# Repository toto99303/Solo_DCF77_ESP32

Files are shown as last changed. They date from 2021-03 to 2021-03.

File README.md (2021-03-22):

# Solo DCF77 ESP32 transmitter
So what is this? It's a standalone DCF77 transmitter designed to be used with any wrist watch that is capable of receiving the signal. (Casio Wave Ceptor series etc.)

#### Features:
- Connects to your local WiFi network.
- Syncs the exact time via NTP and converts it to DCF77 signal.
- Shows the realtime data on the OLED display live.
- Uses screensavers to protect the screen from burn-in. (changes every minute)
- 3D printable stand.

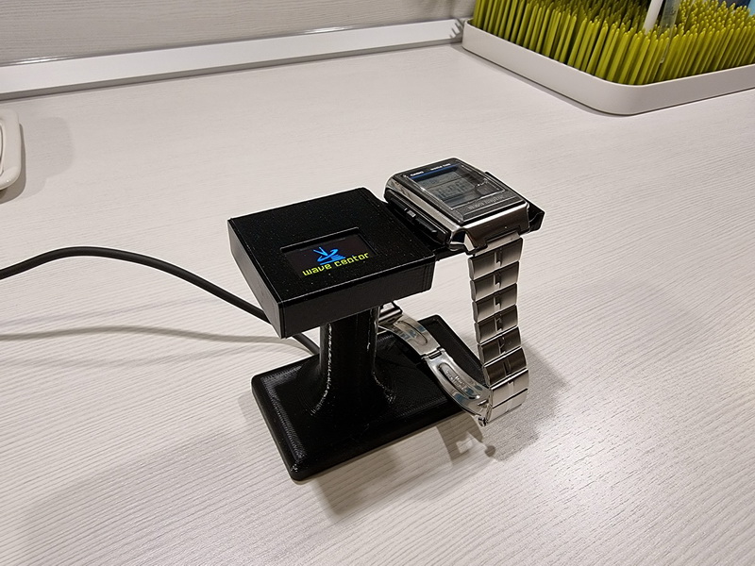
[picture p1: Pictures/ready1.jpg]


### PCB and full BOM:

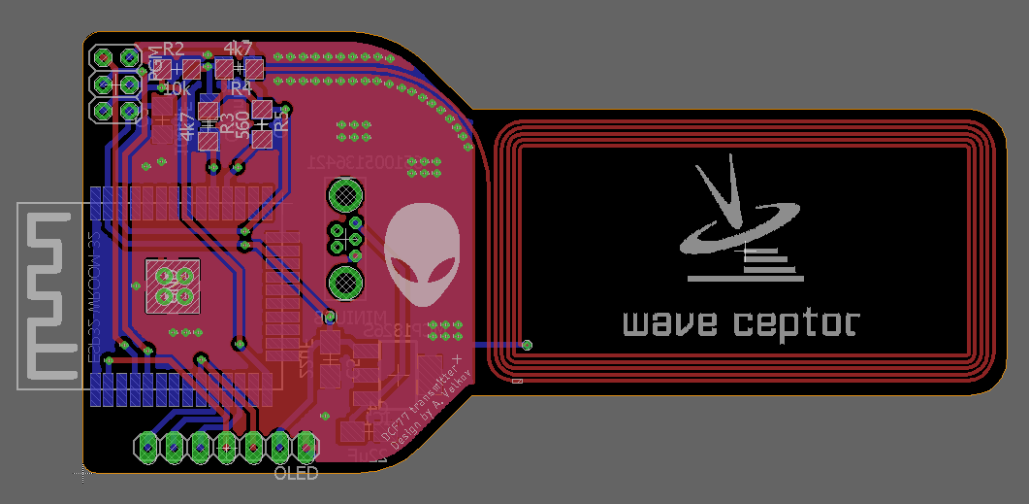
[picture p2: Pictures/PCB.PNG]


The original Eagle design files are included as well as exported GERBER files for direct PCB production.

BOM:
- 1 x ESP32-WROOM-32 barebone
- 1 x 7 Pin SPI 0.96" Dual Color Yellow Blue OLED Display Module SSD1306 (https://hacktronics.co.in/lcd-displays/7-pin-spi-iic-096-dual-color-yellow-blue-oled-display-module-ssd1306)
- 1 x Mini USB female vertical TH (https://store.comet.bg/download-file.php?id=18384)
- 1 x MCP1826S-3302E/DB voltage regulator (https://store.comet.bg/download-file.php?id=4147)
- 3 x TANT B SMD 22uF 16V caps
- 2 x C1206 100nF 50V caps
- 2 x R1206 10K resistors
- 2 x R1206 4.7K resistors
- 1 x R1206 560R resistor

### Firmware
To upload the sketch you will need USB to serial UART converter capable of supplying 3.3V VCC.
Pinout for the header:
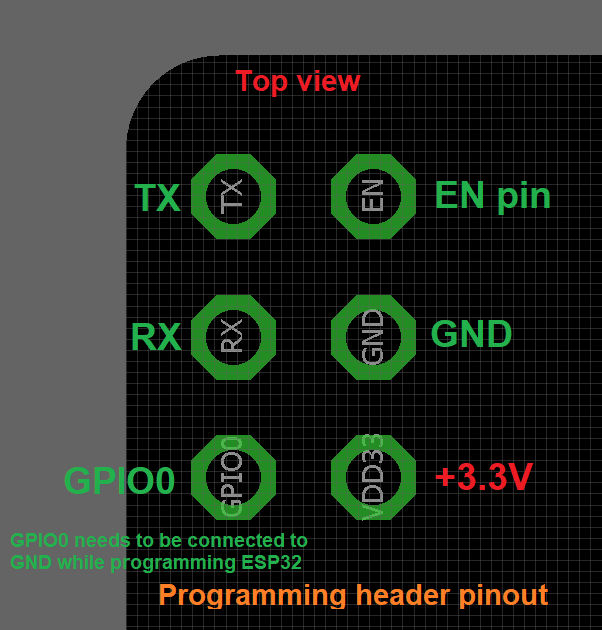
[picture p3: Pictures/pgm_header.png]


Remember that in order to boot the EPS32 in programming mode you will need to connect GPIO0 pin to GND (Low).

1. Open the sketch in Arduino IDE and edit your wifi SSID and password.
2. Use board "WEMOS LOLIN32" at 80Mhz flash frequency. (Tools -> Board)
3. Compile and upload.

### 3D printable stand

The original design file from Fusion360 is available as well as ready to print STLs.
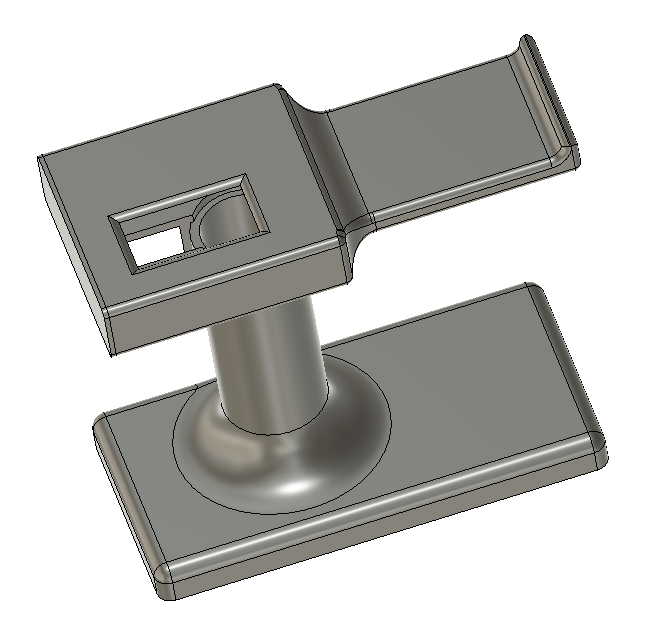
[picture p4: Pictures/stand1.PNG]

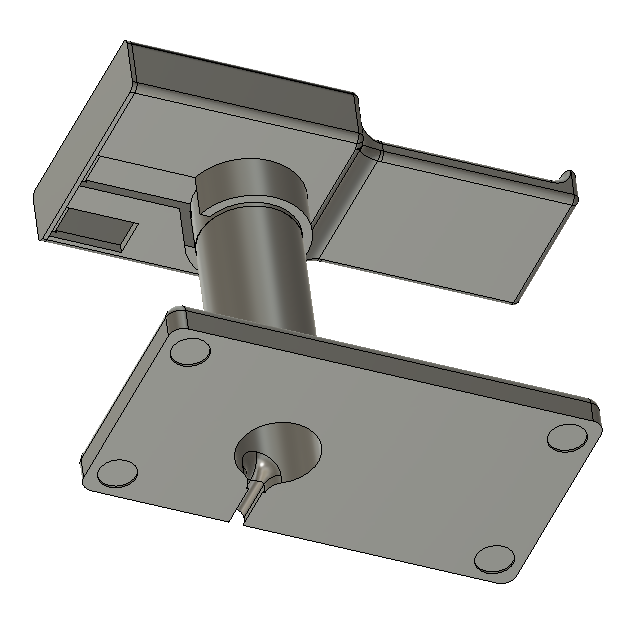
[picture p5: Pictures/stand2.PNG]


### Video:

DCF77 transmitter - demo (https://youtu.be/RjWDWWJ56to)

### More Pictures:

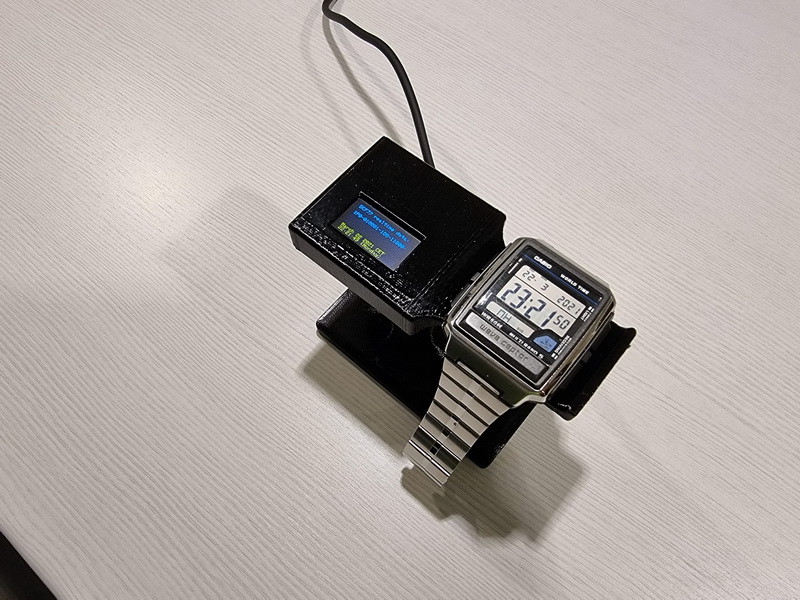
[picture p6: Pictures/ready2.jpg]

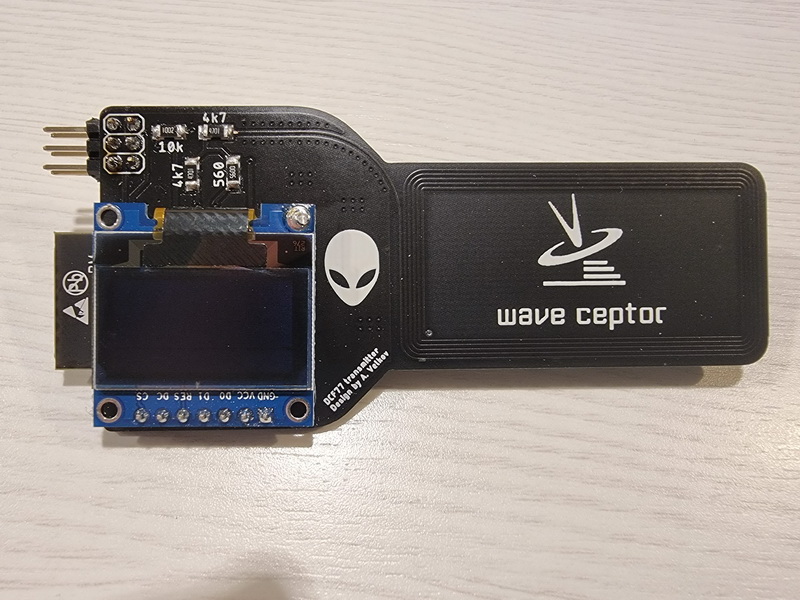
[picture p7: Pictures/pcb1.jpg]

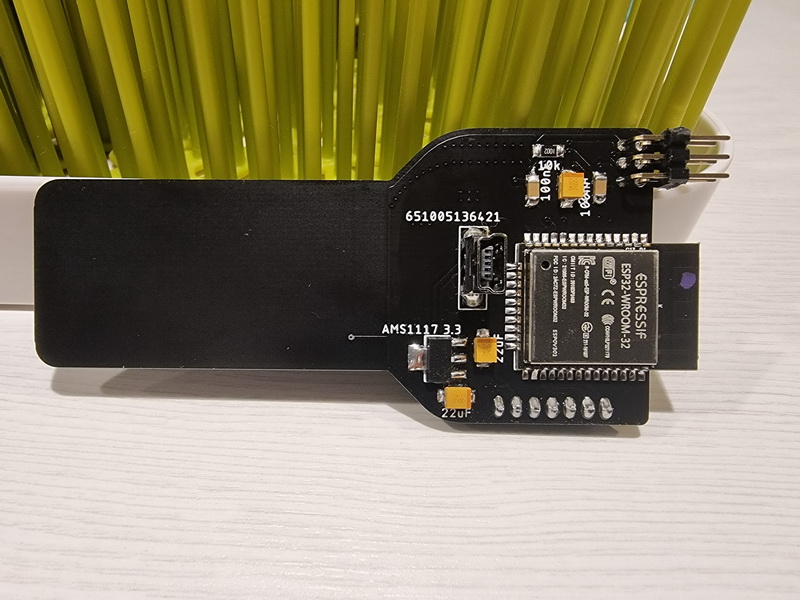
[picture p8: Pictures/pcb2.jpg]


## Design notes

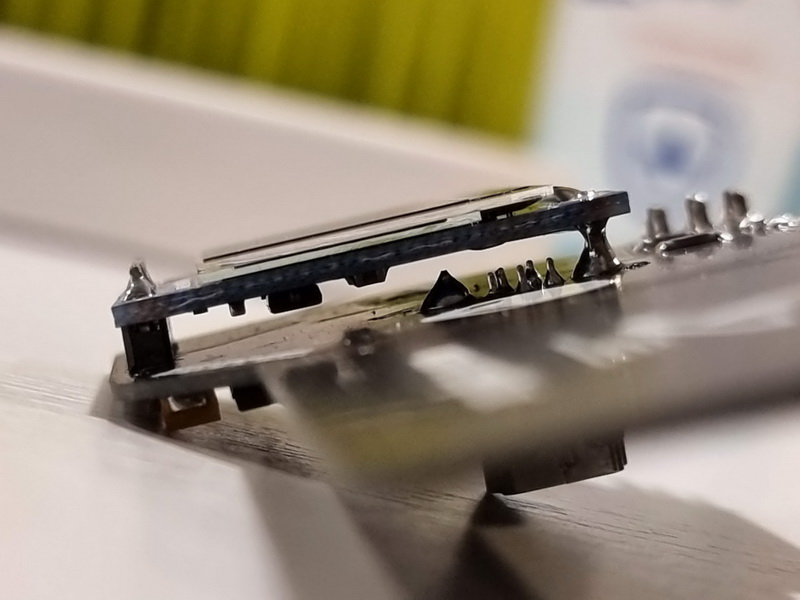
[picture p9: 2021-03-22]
Pictures/oled.jpg

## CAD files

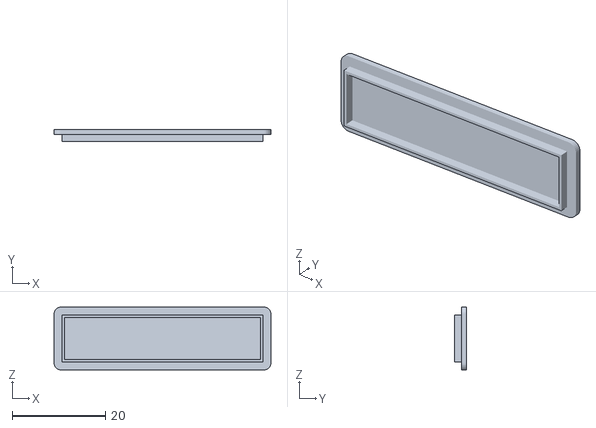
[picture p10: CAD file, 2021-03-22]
Watch stand (3D design)/STL/Cap.stl
46.5 x 2.50 x 13.5

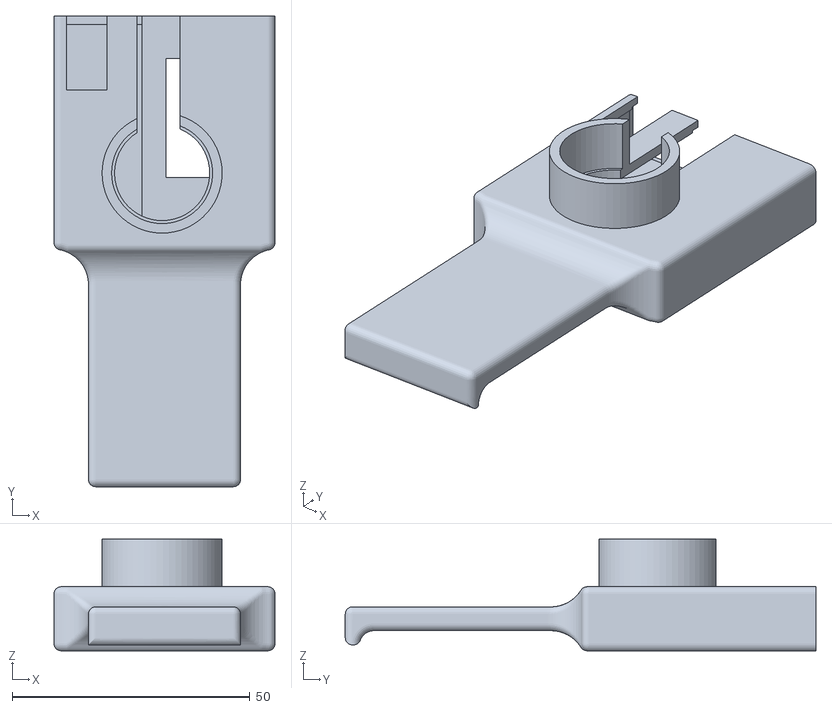
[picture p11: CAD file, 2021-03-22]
Watch stand (3D design)/STL/Top_holder.stl
46.5 x 99.0 x 23.5

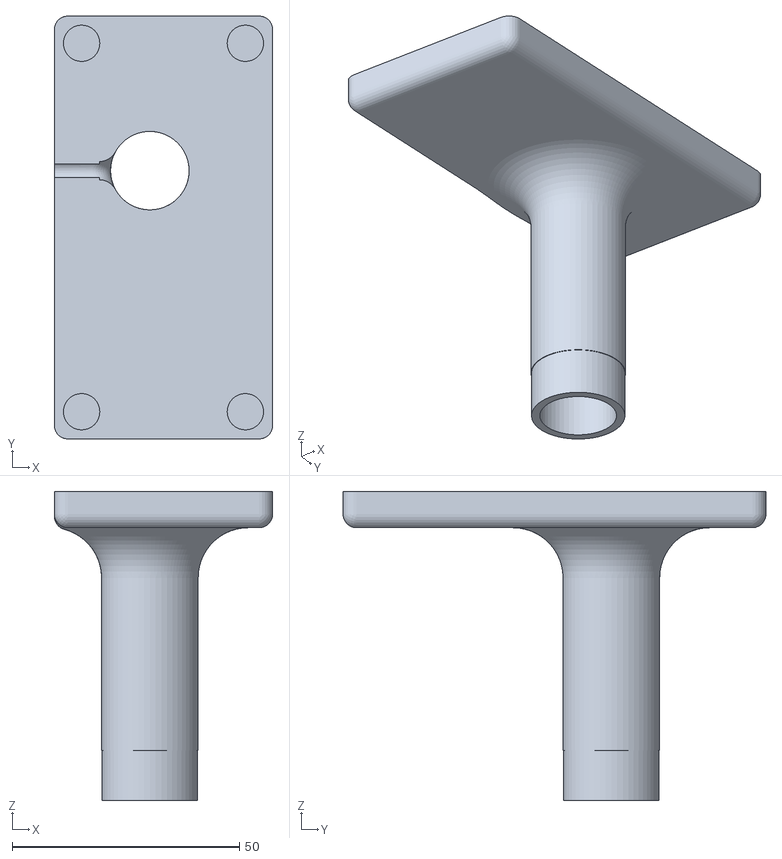
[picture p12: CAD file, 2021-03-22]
Watch stand (3D design)/STL/Bottom_stand.stl
48.0 x 93.0 x 68.0

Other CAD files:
Watch stand (3D design)/Fusion360/Solo_DCF77_ESP32_stand.f3d

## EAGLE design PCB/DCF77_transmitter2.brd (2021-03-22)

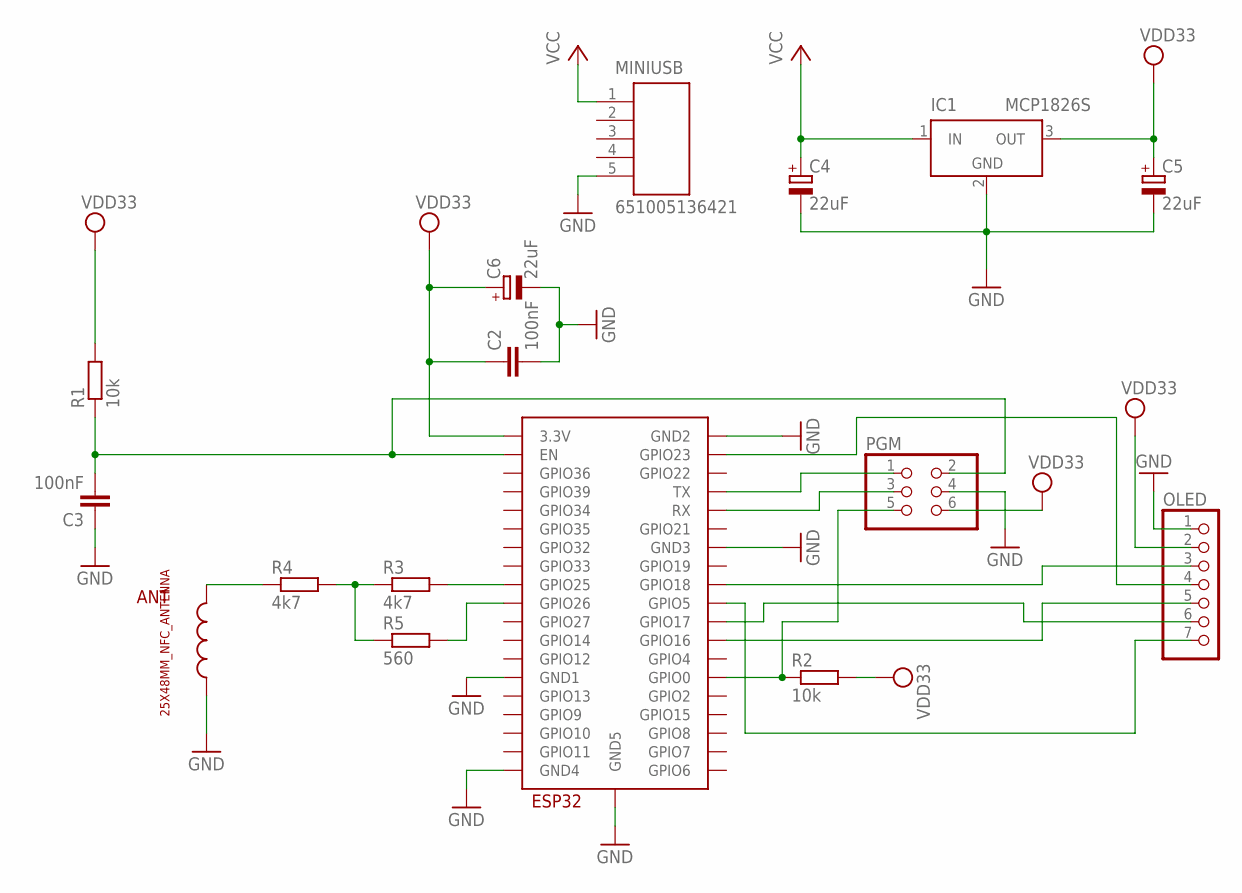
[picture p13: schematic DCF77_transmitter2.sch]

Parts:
ANT: 25X48MM_NFC_ANTENNA
C2, C3: 100nF; C1206
C4, C5, C6: 22uF; B/3528-21W
IC1: MCP1826S; SOT223
MINIUSB: 651005136421
OLED: PINHD-1X7; 1X07
PGM: PINHD-2X3; 2X03
R1, R2: 10k; R1206
R3, R4: 4k7; R1206
R5: 560; R1206
U$2: ESP32-WROOM

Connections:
EN: C3.2, PGM.2, R1.1, U$2.EN
GND: ANT.P$2, C2.2, C3.1, C4.-, C5.-, C6.-, IC1.2 (GND), IC1.4 (GND), MINIUSB.5, OLED.1, PGM.4, U$2.GND1, U$2.GND2, U$2.GND3, U$2.GND4, U$2.GND5
GPIO0: PGM.5, R2.1, U$2.IO0 (GPIO0)
GPIO5: OLED.7, U$2.IO5 (GPIO5)
GPIO16: OLED.5, U$2.IO16 (GPIO16)
GPIO17: OLED.6, U$2.IO17 (GPIO17)
GPIO18: OLED.3, U$2.IO18 (GPIO18)
GPIO23: OLED.4, U$2.IO23 (GPIO23)
unnamed: R5.2, U$2.IO26 (GPIO26)
unnamed: R3.2, U$2.IO25 (GPIO25)
unnamed: R3.1, R4.2, R5.1
unnamed: ANT.P$1, R4.1
RX: PGM.3, U$2.RX
TX: PGM.1, U$2.TX
VCC: C4.+, IC1.1 (IN), MINIUSB.1
VDD33: C2.1, C5.+, C6.+, IC1.3 (OUT), OLED.2, PGM.6, R1.2, R2.2, U$2.3V3 (3.3V)

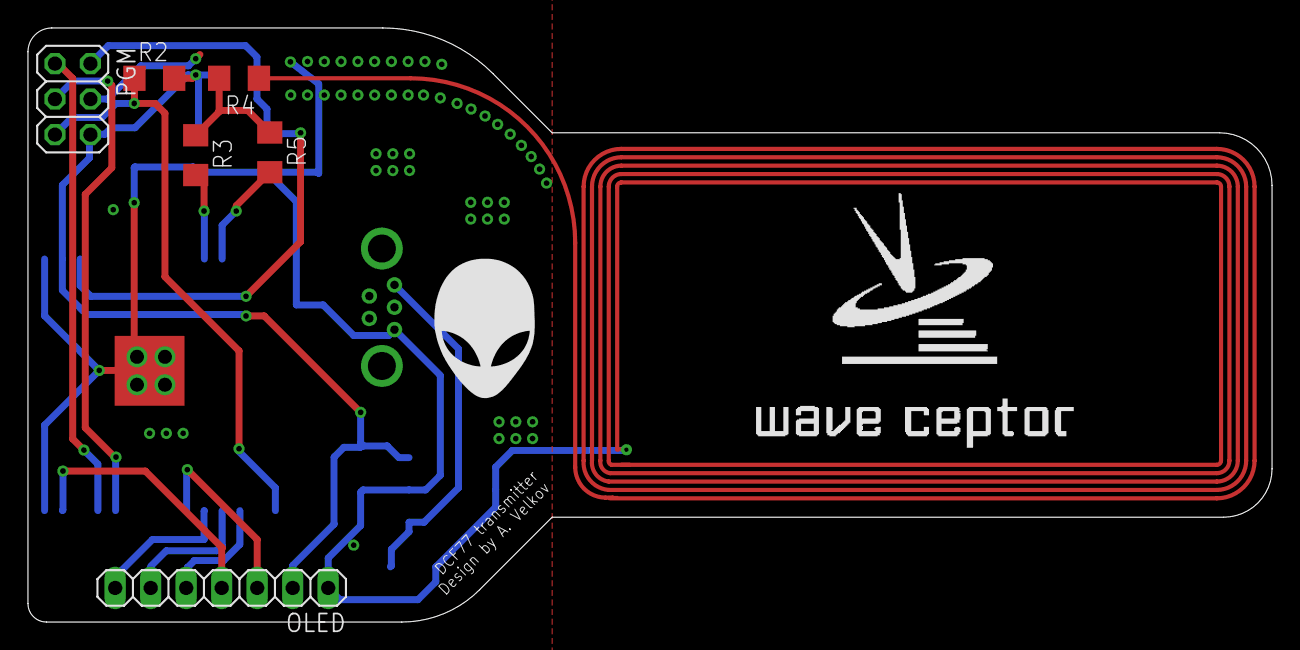
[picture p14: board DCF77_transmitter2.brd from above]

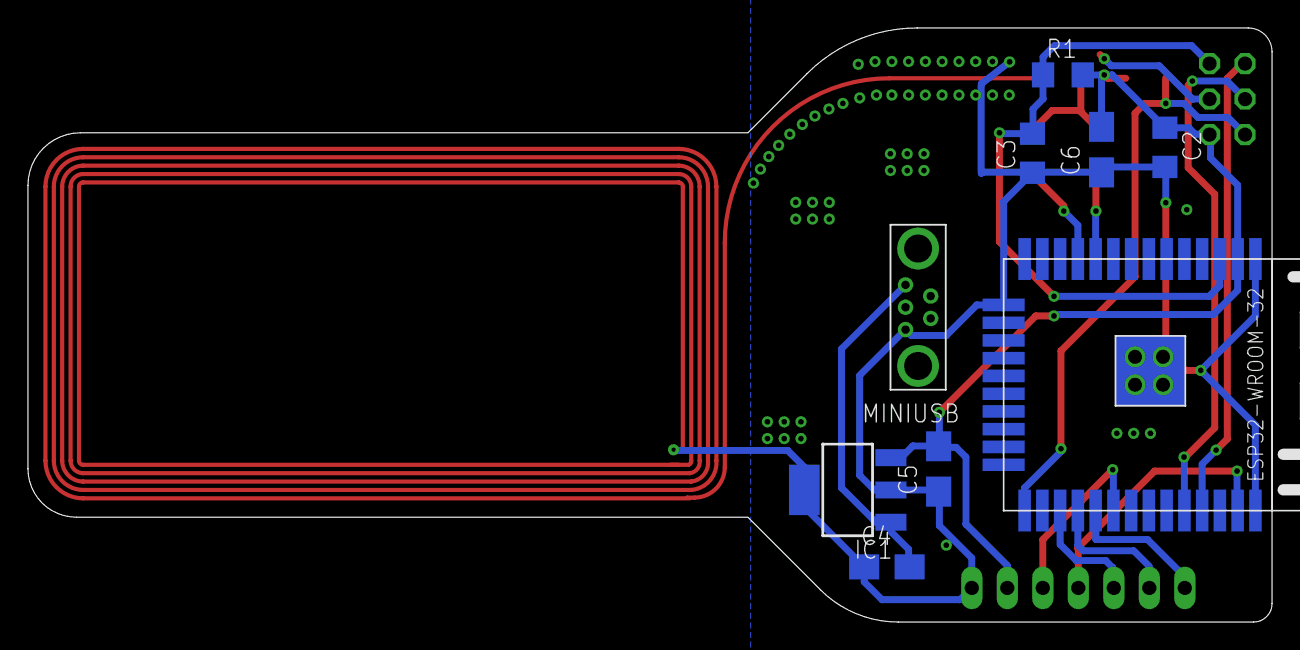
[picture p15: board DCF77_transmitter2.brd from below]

Board: 2 copper layers, 89.0 x 42.5 mm, 16 parts (9 on the bottom side), 16 nets.

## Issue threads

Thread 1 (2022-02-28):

gerber silkscreen vreg ams1117-3.3

Amstrad-nutter, 2022-02-28:
The gerber silkscreen shows vreg ams1117-3.3 which is a common almost generic device but cannot be used "Correct footprint but incorrect pinout.
the BOM listed MCP1826S-3302E with the less common pinout. this works
please recheck your components against the BOM not blindly follow the silkscreen as i did?.

danybd, 2023-05-23:
I had the same issue while reproducing the project. I ordered and built the wrong voltage regulator due to the confusing silkscreen. After some trouble shooting found out that the regulator is not pin compatible.

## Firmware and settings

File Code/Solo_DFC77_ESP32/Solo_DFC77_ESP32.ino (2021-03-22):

/*
  Based on this sketch: https://github.com/SensorsIot/DCF77-Transmitter-for-ESP32
  from Andreas Spiess (the guy with the swiss accent :)

  Modified for my custom Solo DCF77 PCB using ESP32 and SPI OLED display.

  22.03.2021 Antonio Velkov
*/


#include <WiFi.h>
#include <Ticker.h>
#include <Time.h>
#include <Wire.h>  // Only needed for Arduino 1.6.5 and earlier
#include <Adafruit_GFX.h>
#include <Adafruit_SSD1306.h>

//OLED config
#define SCREEN_WIDTH 128 // OLED display width, in pixels
#define SCREEN_HEIGHT 64 // OLED display height, in pixels

#define OLED_MOSI   23
#define OLED_CLK   18
#define OLED_DC    17
#define OLED_CS    5
#define OLED_RESET 16

Adafruit_SSD1306 display(SCREEN_WIDTH, SCREEN_HEIGHT,OLED_MOSI, OLED_CLK, OLED_DC, OLED_RESET, OLED_CS);

// Wifi credentials
const char* ssid = "yourSSID";
const char* password = "yourPassword";
                          
#define LEDBUILTIN 26
#define ANTENNAPIN 25

Ticker tickerDecisec; // TBD at 100ms

//complete array of pulses for a minute
//0 = no pulse, 1=100ms, 2=200ms

int impulseArray[60];
int impulseCount = 0;
int actualHours, actualMinutes, actualSecond, actualDay, actualMonth, actualYear, DayOfW;
int timeRunningContinuous = 0;

const char* ntpServer = "bg.pool.ntp.org"; // enter your closest pool or pool.ntp.org
const char* TZ_INFO    = "CET-1CEST-2,M3.5.0/02:00:00,M10.5.0/03:00:00";  // enter your time zone (https://remotemonitoringsystems.ca/time-zone-abbreviations.php)


struct tm timeinfo;

String time_data;
int screensaver = 0;

//Casio Wave Ceptor custom logo
static const unsigned char PROGMEM logo_bmp[] =
{
  0x00, 0x00, 0x00, 0x00, 0x00, 0x00, 0x01, 0x80, 0x00, 0x00, 0x00, 0x00, 0x00, 0x00, 0x00, 0x00, 
  0x00, 0x00, 0x00, 0x00, 0x00, 0x00, 0x00, 0x80, 0x00, 0x00, 0x00, 0x00, 0x00, 0x00, 0x00, 0x00, 
  0x00, 0x00, 0x00, 0x00, 0x00, 0x00, 0x00, 0x80, 0x00, 0x00, 0x00, 0x00, 0x00, 0x00, 0x00, 0x00, 
  0x00, 0x00, 0x00, 0x00, 0x00, 0x10, 0x00, 0x80, 0x00, 0x00, 0x00, 0x00, 0x00, 0x00, 0x00, 0x00, 
  0x00, 0x00, 0x00, 0x00, 0x00, 0x18, 0x00, 0x80, 0x00, 0x00, 0x00, 0x00, 0x00, 0x00, 0x00, 0x00, 
  0x00, 0x00, 0x00, 0x00, 0x00, 0x08, 0x00, 0x80, 0x00, 0x00, 0x00, 0x00, 0x00, 0x00, 0x00, 0x00, 
  0x00, 0x00, 0x00, 0x00, 0x00, 0x04, 0x00, 0x80, 0x00, 0x00, 0x00, 0x00, 0x00, 0x00, 0x00, 0x00, 
  0x00, 0x00, 0x00, 0x00, 0x00, 0x06, 0x00, 0xc0, 0x00, 0x00, 0x00, 0x00, 0x00, 0x00, 0x00, 0x00, 
  0x00, 0x00, 0x00, 0x00, 0x00, 0x02, 0x00, 0xc0, 0x00, 0x00, 0x00, 0x00, 0x00, 0x00, 0x00, 0x00, 
  0x00, 0x00, 0x00, 0x00, 0x00, 0x01, 0x00, 0xc0, 0x00, 0x00, 0x00, 0x00, 0x00, 0x00, 0x00, 0x00, 
  0x00, 0x00, 0x00, 0x00, 0x00, 0x01, 0x80, 0xc0, 0x00, 0x00, 0x00, 0x00, 0x00, 0x00, 0x00, 0x00, 
  0x00, 0x00, 0x00, 0x00, 0x00, 0x00, 0xc0, 0xc0, 0x00, 0x00, 0x00, 0x00, 0x00, 0x00, 0x00, 0x00, 
  0x00, 0x00, 0x00, 0x00, 0x00, 0x00, 0xc0, 0xc0, 0x00, 0x00, 0x00, 0x00, 0x00, 0x00, 0x00, 0x00, 
  0x00, 0x00, 0x00, 0x00, 0x00, 0x00, 0x60, 0xc0, 0x00, 0x00, 0x00, 0x00, 0x00, 0x00, 0x00, 0x00, 
  0x00, 0x00, 0x00, 0x00, 0x00, 0x00, 0x30, 0xe0, 0x00, 0x00, 0x00, 0x00, 0x00, 0x00, 0x00, 0x00, 
  0x00, 0x00, 0x00, 0x00, 0x00, 0x00, 0x38, 0xe0, 0x00, 0x00, 0x00, 0x00, 0x00, 0x00, 0x00, 0x00, 
  0x00, 0x00, 0x00, 0x00, 0x00, 0x00, 0x1c, 0xe0, 0x00, 0x00, 0x00, 0x00, 0x00, 0x00, 0x00, 0x00, 
  0x00, 0x00, 0x00, 0x00, 0x00, 0x00, 0x1e, 0xe0, 0x00, 0x7e, 0x00, 0x00, 0x00, 0x00, 0x00, 0x00, 
  0x00, 0x00, 0x00, 0x00, 0x00, 0x00, 0x0f, 0xe0, 0x07, 0xff, 0xc0, 0x00, 0x00, 0x00, 0x00, 0x00, 
  0x00, 0x00, 0x00, 0x00, 0x00, 0x00, 0x07, 0xf0, 0x00, 0x1f, 0xc0, 0x00, 0x00, 0x00, 0x00, 0x00, 
  0x00, 0x00, 0x00, 0x00, 0x00, 0x00, 0x07, 0xf0, 0x00, 0x1f, 0xc0, 0x00, 0x00, 0x00, 0x00, 0x00, 
  0x00, 0x00, 0x00, 0x00, 0x00, 0x00, 0x03, 0xf0, 0x00, 0x3f, 0x80, 0x00, 0x00, 0x00, 0x00, 0x00, 
  0x00, 0x00, 0x00, 0x00, 0x00, 0x00, 0x03, 0xf0, 0x00, 0x7f, 0x00, 0x00, 0x00, 0x00, 0x00, 0x00, 
  0x00, 0x00, 0x00, 0x00, 0x00, 0x00, 0x01, 0xf0, 0x00, 0xfe, 0x00, 0x00, 0x00, 0x00, 0x00, 0x00, 
  0x00, 0x00, 0x00, 0x00, 0x00, 0x00, 0x00, 0xf0, 0x03, 0xfc, 0x00, 0x00, 0x00, 0x00, 0x00, 0x00, 
  0x00, 0x00, 0x00, 0x00, 0x00, 0x00, 0x80, 0xf0, 0x07, 0xf0, 0x00, 0x00, 0x00, 0x00, 0x00, 0x00, 
  0x00, 0x00, 0x00, 0x00, 0x00, 0x03, 0x00, 0x70, 0x1f, 0xe0, 0x00, 0x00, 0x00, 0x00, 0x00, 0x00, 
  0x00, 0x00, 0x00, 0x00, 0x00, 0x0c, 0x00, 0x00, 0xff, 0x80, 0x00, 0x00, 0x00, 0x00, 0x00, 0x00, 
  0x00, 0x00, 0x00, 0x00, 0x00, 0x18, 0x00, 0x03, 0xfe, 0x00, 0x00, 0x00, 0x00, 0x00, 0x00, 0x00, 
  0x00, 0x00, 0x00, 0x00, 0x00, 0x70, 0x00, 0x1f, 0xf8, 0x00, 0x00, 0x00, 0x00, 0x00, 0x00, 0x00, 
  0x00, 0x00, 0x00, 0x00, 0x00, 0xe0, 0x00, 0xff, 0xc0, 0x00, 0x00, 0x00, 0x00, 0x00, 0x00, 0x00, 
  0x00, 0x00, 0x00, 0x00, 0x01, 0xf0, 0x0f, 0xff, 0x00, 0x00, 0x00, 0x00, 0x00, 0x00, 0x00, 0x00, 
  0x00, 0x00, 0x00, 0x00, 0x03, 0xff, 0xff, 0xf8, 0x00, 0x00, 0x00, 0x00, 0x00, 0x00, 0x00, 0x00, 
  0x00, 0x00, 0x00, 0x00, 0x07, 0xff, 0xff, 0xc3, 0xff, 0xf8, 0x00, 0x00, 0x00, 0x00, 0x00, 0x00, 
  0x00, 0x00, 0x00, 0x00, 0x07, 0xff, 0xfe, 0x03, 0xff, 0xe0, 0x00, 0x00, 0x00, 0x00, 0x00, 0x00, 
  0x00, 0x00, 0x00, 0x00, 0x07, 0xff, 0xc0, 0x00, 0x00, 0x00, 0x00, 0x00, 0x00, 0x00, 0x00, 0x00, 
  0x00, 0x00, 0x00, 0x00, 0x01, 0xfc, 0x00, 0x00, 0x00, 0x00, 0x00, 0x00, 0x00, 0x00, 0x00, 0x00, 
  0x00, 0x00, 0x00, 0x00, 0x00, 0x00, 0x00, 0x03, 0xff, 0xfe, 0x00, 0x00, 0x00, 0x00, 0x00, 0x00, 
  0x00, 0x00, 0x00, 0x00, 0x00, 0x00, 0x00, 0x03, 0xff, 0xfc, 0x00, 0x00, 0x00, 0x00, 0x00, 0x00, 
  0x00, 0x00, 0x00, 0x00, 0x00, 0x00, 0x00, 0x00, 0x00, 0x00, 0x00, 0x00, 0x00, 0x00, 0x00, 0x00, 
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
};

void setup() {
  esp_sleep_disable_wakeup_source(ESP_SLEEP_WAKEUP_ALL);

  Serial.begin(115200);
  Serial.println();
  Serial.println("DCF77 transmitter");
  display.begin(SSD1306_SWITCHCAPVCC);
  display.clearDisplay();
  display.setTextSize(1);
  display.setTextColor(SSD1306_WHITE);
  display.setRotation(2);
  display.setCursor(0, 0);
  display.cp437(true);
  display.println(F("DCF77 transmitter"));
  display.println(F("v1.0 @2021"));
  display.println();
  display.println(F("A. Velkov"));
  display.display();
  delay(3000);
  drawlogo();
  delay(5000);


  ledcSetup(0, 77500, 8); // DCF77 frequency
  ledcAttachPin(ANTENNAPIN, 0); // Antenna pin

  pinMode (LEDBUILTIN, OUTPUT);
  digitalWrite (LEDBUILTIN, LOW); // LOW if LEDBUILTIN is inverted (like in Wemos boards)

  WiFi_on();
  getNTP();
  WiFi_off();

  CodeTime();

  // sync to the start of a second
  Serial.print("Syncing... ");
   
  int startSecond = timeinfo.tm_sec;
  long count = 0;
  do {
    count++;
    if(!getLocalTime(&timeinfo)){
      Serial.println("Error obtaining time...");
      display.clearDisplay();
      display.setCursor(0, 0);
      display.println(F("Error obtaining time..."));
      display.display();
      delay(3000);
      ESP.restart();
    }
  } while (startSecond == timeinfo.tm_sec);
  
  Serial.print(&timeinfo, "Time now: %B %d %Y %H:%M:%S (%A) %Z ");
  if (timeinfo.tm_isdst == 0) {
    Serial.println("DST=OFF");
  } else {
    Serial.println("DST=ON");
  }
  
  tickerDecisec.attach_ms(100, DcfOut); // from now on calls DcfOut every 100ms
  Serial.print("Ok ");
  Serial.println(count);
  
}

void loop() {
  // There is no code inside the loop. This is a syncronous program driven by the Ticker
}

void CodeTime() {
  DayOfW = timeinfo.tm_wday;
  if (DayOfW == 0) DayOfW = 7;
  actualDay = timeinfo.tm_mday;
  actualMonth = timeinfo.tm_mon + 1;
  actualYear = timeinfo.tm_year - 100;
  actualHours = timeinfo.tm_hour;
  actualMinutes = timeinfo.tm_min + 1; // DCF77 transmitts the next minute
  if (actualMinutes >= 60) {
    actualMinutes = 0;
    actualHours++;
  }
  actualSecond = timeinfo.tm_sec; 
  if (actualSecond == 60) actualSecond = 0;

  int n, Tmp, TmpIn;
  int ParityCount = 0;

  //we put the first 20 bits of each minute at a logical zero value
  for (n = 0; n < 20; n++) impulseArray[n] = 1;
  
  // set DST bit
  if (timeinfo.tm_isdst == 0) {
    impulseArray[18] = 2; // CET or DST OFF
  } else {
    impulseArray[17] = 2; // CEST or DST ON
  }
  
  //bit 20 must be 1 to indicate active time
  impulseArray[20] = 2;

  //calculates the bits for the minutes
  TmpIn = Bin2Bcd(actualMinutes);
  for (n = 21; n < 28; n++) {
    Tmp = TmpIn & 1;
    impulseArray[n] = Tmp + 1;
    ParityCount += Tmp;
    TmpIn >>= 1;
  }
  if ((ParityCount & 1) == 0)
    impulseArray[28] = 1;
  else
    impulseArray[28] = 2;

  //calculates bits for the hours
  ParityCount = 0;
  TmpIn = Bin2Bcd(actualHours);
  for (n = 29; n < 35; n++) {
    Tmp = TmpIn & 1;
    impulseArray[n] = Tmp + 1;
    ParityCount += Tmp;
    TmpIn >>= 1;
  }
  if ((ParityCount & 1) == 0)
    impulseArray[35] = 1;
  else
    impulseArray[35] = 2;
  ParityCount = 0;

  //calculate the bits for the actual Day of Month
  TmpIn = Bin2Bcd(actualDay);
  for (n = 36; n < 42; n++) {
    Tmp = TmpIn & 1;
    impulseArray[n] = Tmp + 1;
    ParityCount += Tmp;
    TmpIn >>= 1;
  }
  TmpIn = Bin2Bcd(DayOfW);
  for (n = 42; n < 45; n++) {
    Tmp = TmpIn & 1;
    impulseArray[n] = Tmp + 1;
    ParityCount += Tmp;
    TmpIn >>= 1;
  }
  //calculates the bits for the actualMonth
  TmpIn = Bin2Bcd(actualMonth);
  for (n = 45; n < 50; n++) {
    Tmp = TmpIn & 1;
    impulseArray[n] = Tmp + 1;
    ParityCount += Tmp;
    TmpIn >>= 1;
  }
  //calculates the bits for actual year
  TmpIn = Bin2Bcd(actualYear);   // 2 digit year
  for (n = 50; n < 58; n++) {
    Tmp = TmpIn & 1;
    impulseArray[n] = Tmp + 1;
    ParityCount += Tmp;
    TmpIn >>= 1;
  }
  //equal date
  if ((ParityCount & 1) == 0)
    impulseArray[58] = 1;
  else
    impulseArray[58] = 2;

  //last missing pulse
  impulseArray[59] = 0; // No pulse
}

int Bin2Bcd(int dato) {
  int msb, lsb;
  if (dato < 10)
    return dato;
  msb = (dato / 10) << 4;
  lsb = dato % 10;
  return msb + lsb;
}

void DcfOut() {
  switch (impulseCount++) {
    case 0:
      if (impulseArray[actualSecond] != 0) {
        digitalWrite(LEDBUILTIN, LOW);
        ledcWrite(0, 0);
      }
      break;
    case 1:
      if (impulseArray[actualSecond] == 1) {
        digitalWrite(LEDBUILTIN, HIGH);
        ledcWrite(0, 127);
      }
      break;
    case 2:
      digitalWrite(LEDBUILTIN, HIGH);
      ledcWrite(0, 127);
      break;
    case 9:
      impulseCount = 0;

      if (actualSecond == 1 || actualSecond == 15 || actualSecond == 21  || actualSecond == 29 ) {
        Serial.print("-");
        time_data+="-";
        show_time(time_data,screensaver,actualSecond);
      }
      if (actualSecond == 36  || actualSecond == 42 || actualSecond == 45  || actualSecond == 50 ) {
        Serial.print("-");
        time_data+="-";
        show_time(time_data,screensaver,actualSecond);
      }
      if (actualSecond == 28  || actualSecond == 35  || actualSecond == 58 ) {
        Serial.print("P");
        time_data+="P";
        show_time(time_data,screensaver,actualSecond);
      }

      if (impulseArray[actualSecond] == 1) {
        Serial.print("0");
        time_data+="0";
        show_time(time_data,screensaver,actualSecond);
      }
      if (impulseArray[actualSecond] == 2) {
        Serial.print("1");
        time_data+="1";
        show_time(time_data,screensaver,actualSecond);
      }

      if (actualSecond == 59 ) {
        Serial.println();
        
        if (screensaver >= 6) {
        screensaver = 1;
        } else screensaver++;
        
        time_data="";
        show_time(time_data,screensaver,actualSecond);

        timeRunningContinuous++;
        if (timeRunningContinuous > 360) ESP.restart(); // 6 hours running, then restart all over

      }
      break;
  }
  if(!getLocalTime(&timeinfo)){
    Serial.println("Error obtaining time...");
    display.clearDisplay();
    display.setCursor(0, 0);
    display.println(F("Error obtaining time..."));
    display.display();
    delay(3000);
    ESP.restart();
  }
  CodeTime();
}

void drawrect(void) {
  display.clearDisplay();

  for(int16_t i=0; i<display.height()/2; i+=2) {
    display.drawRect(i, i, display.width()-2*i, display.height()-2*i, SSD1306_WHITE);
    display.display();
  }
}

void fillrect(void) {
  display.clearDisplay();

  for(int16_t i=0; i<display.height()/2; i+=3) {
    // The INVERSE color is used so rectangles alternate white/black
    display.fillRect(i, i, display.width()-i*2, display.height()-i*2, SSD1306_INVERSE);
    display.display();
  }
}

void drawlogo(void) {
  display.clearDisplay();
  display.drawBitmap(0, 0, logo_bmp, 128, 64, WHITE);
  display.display();
}

void getNTP() {
  Serial.print("GetNTP ");
  display.clearDisplay();
  display.setCursor(0, 0);
  display.println(F("Syncing NTP..."));
  int i = 0;
  do {
    i++;
    if (i > 40) {
      ESP.restart();
    }
    configTime(0, 0, ntpServer);
    setenv("TZ", TZ_INFO, 1);
    delay(500);
  } while (!getLocalTime(&timeinfo));
  Serial.println("Ok");
  display.println();
  display.println(F("Done!"));
  display.display();
  delay(2000);
}

void show_time(String time_data,int screensaver,int actualSecond) {

  if (screensaver==0 || screensaver==2 || screensaver==4 || screensaver==6) {
  display.clearDisplay();
  display.setCursor(0, 48);
  display.println(&timeinfo, "%B %d %Y %Z");
  display.println(&timeinfo, "%H:%M:%S (%A)");
  display.setCursor(0, 0);
  display.println(F("DCF77 realtime data:"));
  display.println();
  display.println(time_data);
  display.display();
  }

  if (screensaver == 1 && actualSecond == 59) drawlogo();
  if (screensaver == 3 && actualSecond == 59) drawrect();
  if (screensaver == 5 && actualSecond == 59) fillrect();
}

void WiFi_on() {
  
  byte mac[6];
  
  Serial.print("Connecting to: "+String(ssid));
  display.clearDisplay();
  display.setCursor(0, 0);
  display.println(F("Connecting WiFi to:"));
  display.println(ssid);
  display.println("...");
  display.display();
  delay(500);
  
  WiFi.begin(ssid, password);
  int counter = 0;
  while (WiFi.status() != WL_CONNECTED) {
    delay(500);
    if (counter > 20) ESP.restart();
    Serial.print ( "." );
    counter++;
  }
  Serial.println();
  Serial.println("WiFi connected");
  display.clearDisplay();
  display.setCursor(0, 0);
  display.println(F("Connecting WiFi to:"));
  display.println(ssid);
  display.println(F("Connected!"));
  display.println();
  display.println(WiFi.localIP());
  display.println();
  WiFi.macAddress(mac);
  display.print(mac[5],HEX);
  display.print(":");
  display.print(mac[4],HEX);
  display.print(":");
  display.print(mac[3],HEX);
  display.print(":");
  display.print(mac[2],HEX);
  display.print(":");
  display.print(mac[1],HEX);
  display.print(":");
  display.println(mac[0],HEX);
  
  display.display();
  delay(5000);
}

void WiFi_off() {
  WiFi.disconnect(true);
  WiFi.mode(WIFI_OFF);
  Serial.println("WiFi disconnected");
  Serial.flush();
}

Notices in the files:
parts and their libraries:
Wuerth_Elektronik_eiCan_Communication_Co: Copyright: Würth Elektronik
